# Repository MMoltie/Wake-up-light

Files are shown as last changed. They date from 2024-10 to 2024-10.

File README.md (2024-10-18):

# Wake-up-light

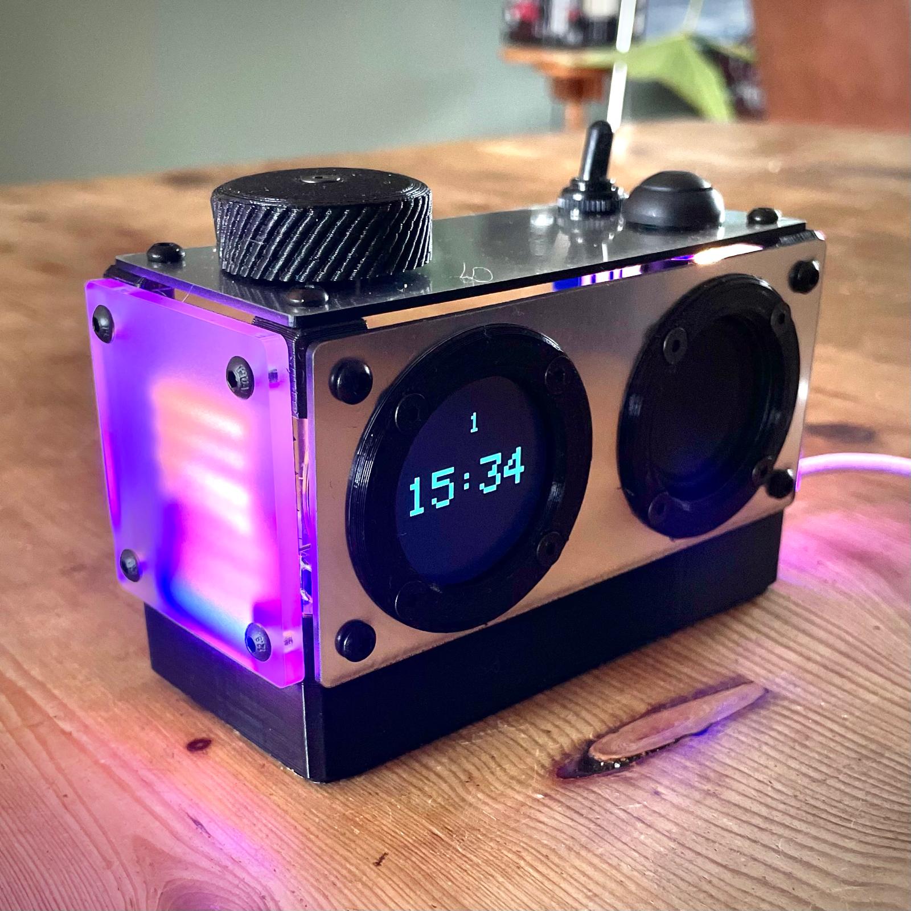
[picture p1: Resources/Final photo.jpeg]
Photo of the projects results


The Wake-up light is a 2-in-1 alarm clock and reading light. 20 minutes before the alarm goes off, LED bars will slowly start to light up, being fully lit and sounding a calming alarm sound when the time to wake is reached. To use the reading light function simply turn the knob to the desired reading time. 10 minutes before the end the lights will slowly dim, helping the reader to gently fall asleep.

#arduino #DIY #wakeup-light #3dprinting #pcb-design #alarmclock 

## Links:

3D model - https://cad.onshape.com/documents/af6c3aa3524b6fd9ad475df8/w/6b9f407a1e785059fe354a23/e/e36683b730fa269897eac513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

PCB - https://oshwlab.com/marliesmoltmaker/wake-up-light_copy

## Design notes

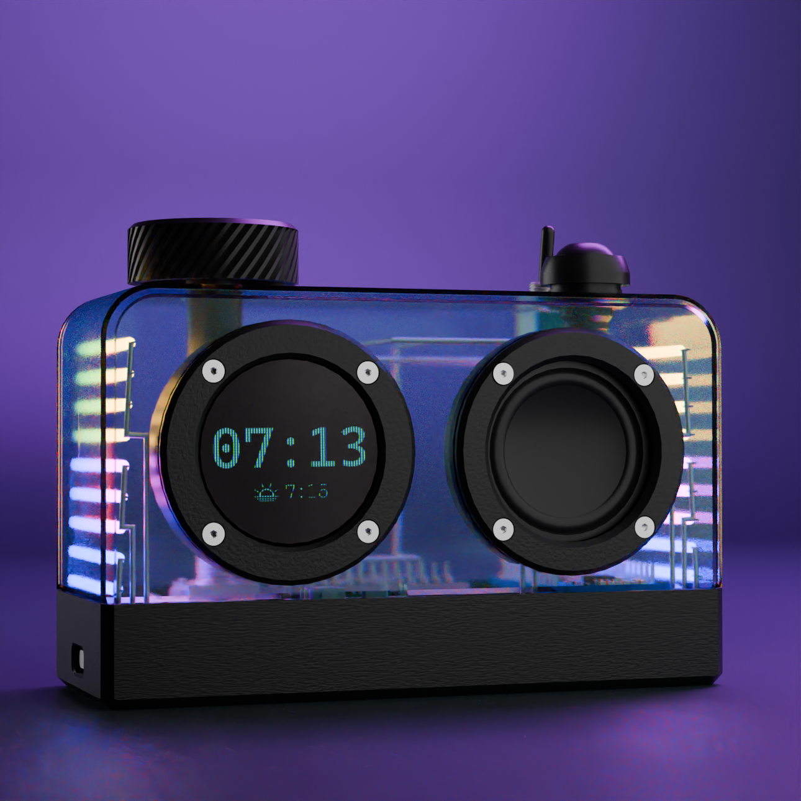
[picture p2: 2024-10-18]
Resources/Render.png

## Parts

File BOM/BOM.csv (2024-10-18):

Qty | Name | Manufacturer | Specification
Purchase
1 | Controller | Arduino | Nano USB-C
1 | RTC | DFRobot | Fermion SD3031
1 | Display |  | 1.28 inch GC9A01
1 | Audio board |  | BY8301-16P
1 | Buck converter |  | MP1584
1 | USB port
3 | Transistor |  | TIP120 60V 5A
4 | LED bar – blue |  | 38mm 3V
6 | LED bar – pruple |  | 38mm 3V
8 | LED bar – orange |  | 38mm 3V
1 | Rotary encoder |  | EC11 15mm half handle
1 | Push Button |  | PBS-33B
1 | Toggle switch |  | MTS-102
1 | Toggle switch cover |  | MTS-XXX
24 | M3 Button |  | M3x6mm, button head
9 | M3 countersunk |  | M3x6mm, countersunk
9 | Insert |  | M3 metal insert
1 | Speaker | Dayton Audio | CE36-8
1 | Wire |  | Single core – 1.5mm
4 | Resistor |  | 1K
1 | Capacitor |  | 1000 uF 25V
Manufacture
1 | Front plate |  | 1.2mm
2 | Side plate |  | 2mm
1 | Back plate |  | 1.2mm
1 | Top plate |  | 1.2mm
1 | Bottom case |  | PLA
4 | Corner connector |  | PLA

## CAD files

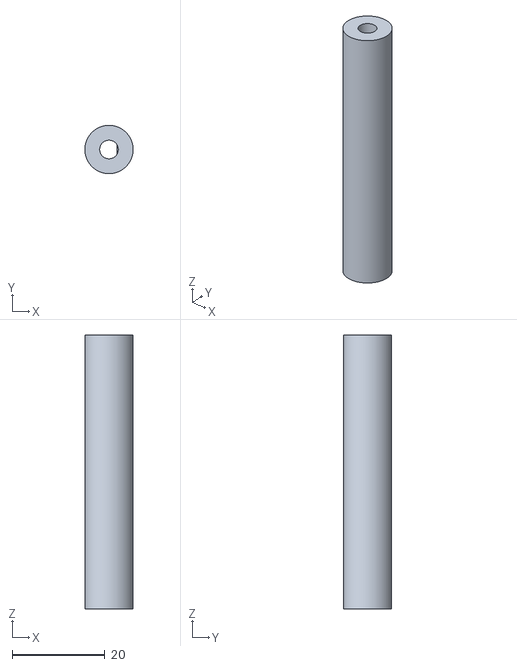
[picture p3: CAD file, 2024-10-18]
CAD/3D print STL/M02003 - Rot knob stem.stl
10.4 x 10.4 x 59.0

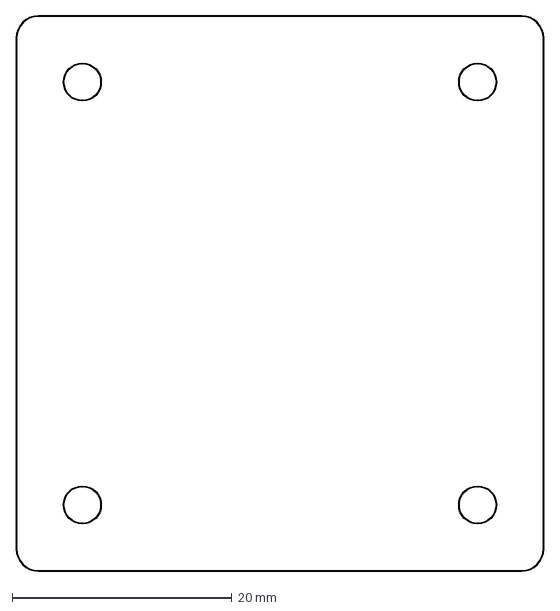
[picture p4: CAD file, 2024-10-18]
CAD/Lasercut STL/M02001d - right plate (2x).dxf
48.0 x 50.5 mm

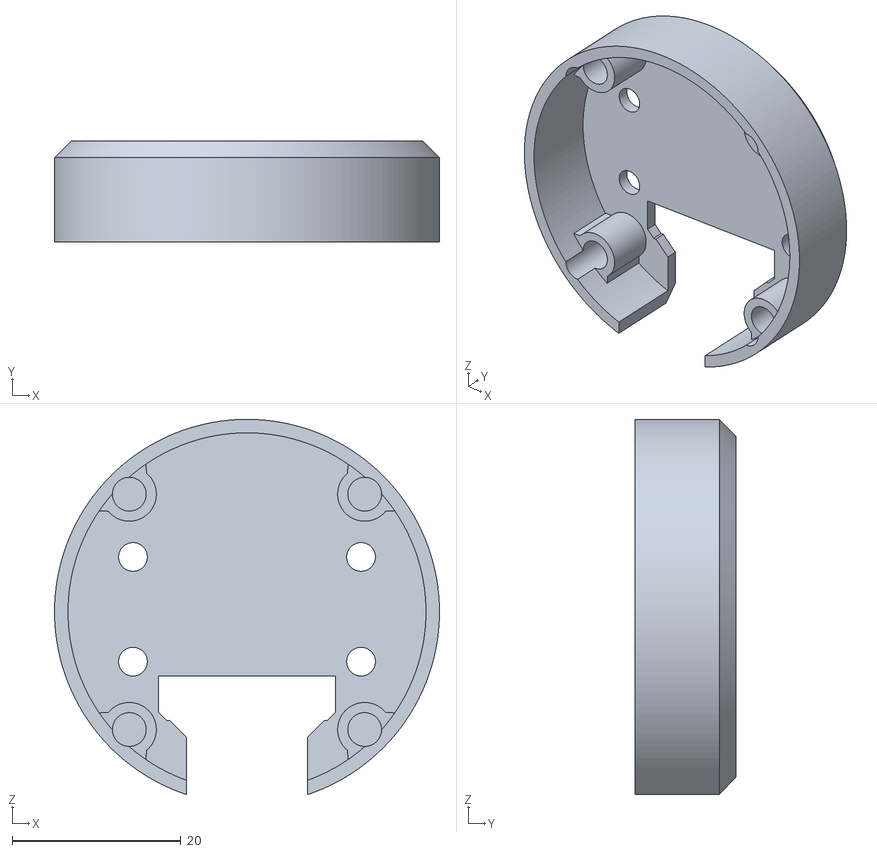
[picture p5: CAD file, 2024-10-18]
CAD/3D print STL/M02007 - Back rim.stl
45.6 x 12.0 x 44.4

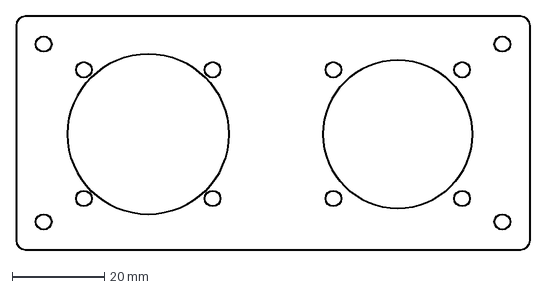
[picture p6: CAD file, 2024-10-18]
CAD/Lasercut STL/M02001a - front plate.dxf
111.3 x 50.5 mm

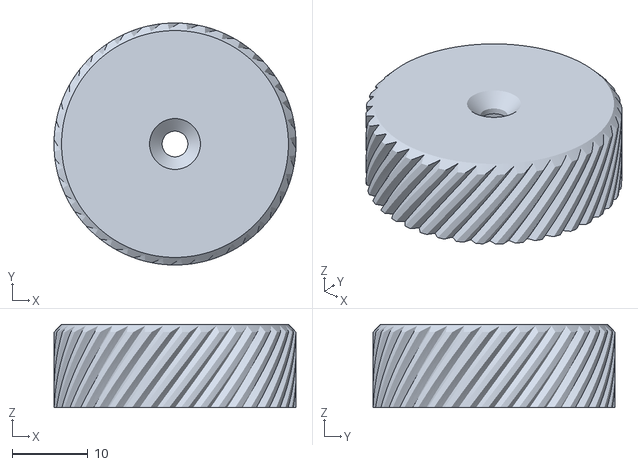
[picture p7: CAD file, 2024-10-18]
CAD/3D print STL/M02003b - Rot knob top.stl
32.0 x 32.0 x 11.0

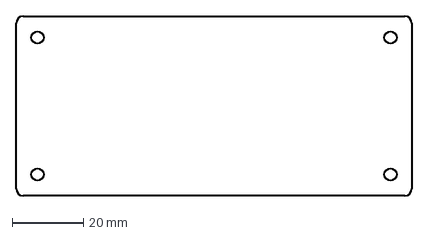
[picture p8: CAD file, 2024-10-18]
CAD/Lasercut STL/M02001b - back plate.dxf
111.3 x 50.5 mm

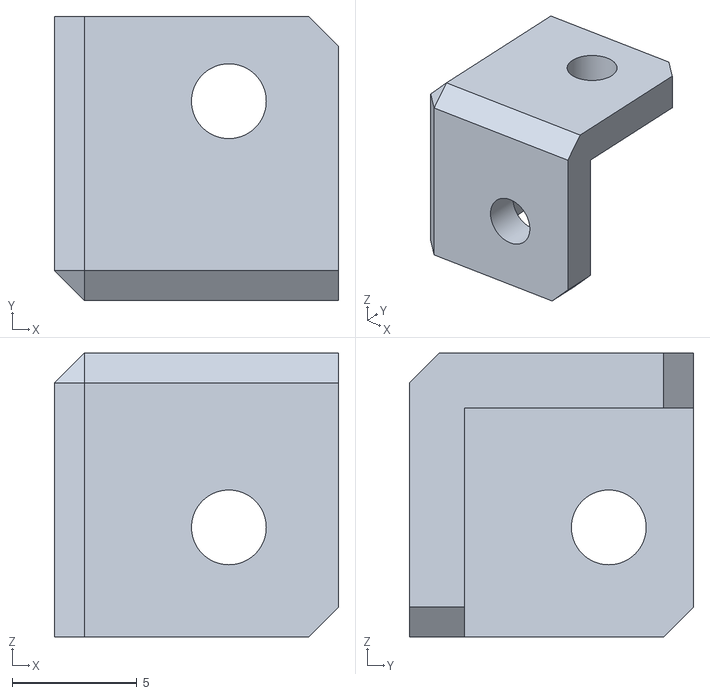
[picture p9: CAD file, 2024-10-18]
CAD/3D print STL/M02010 - CornerConnector.stl
11.4 x 11.4 x 11.4

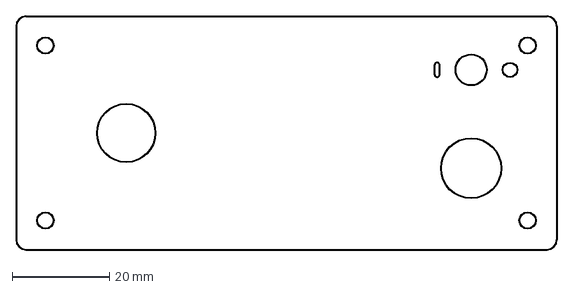
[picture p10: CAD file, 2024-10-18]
CAD/Lasercut STL/M02001e- top plate.dxf
111.3 x 48.0 mm

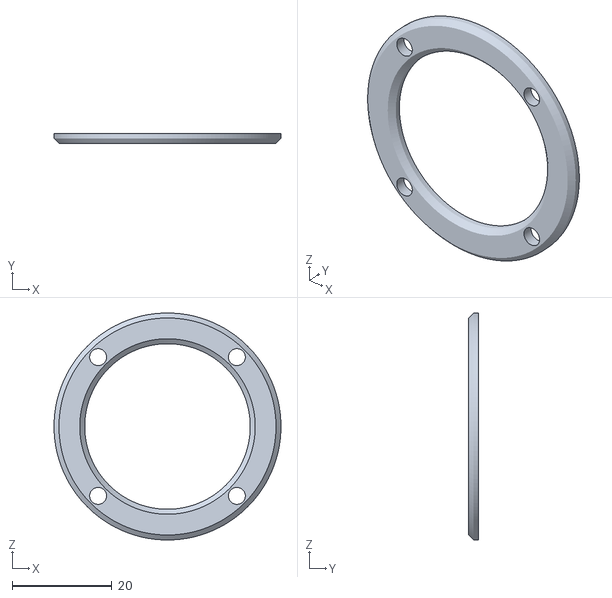
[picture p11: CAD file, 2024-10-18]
CAD/3D print STL/M02006 - Front rim.stl
45.6 x 2.00 x 45.6

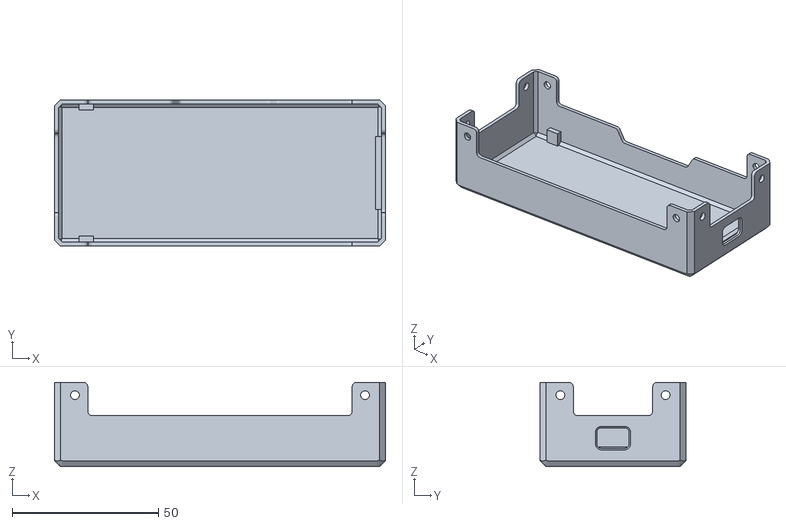
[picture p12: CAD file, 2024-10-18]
CAD/3D print STL/M02002 - Bottom case.stl
113.3 x 50.0 x 28.9

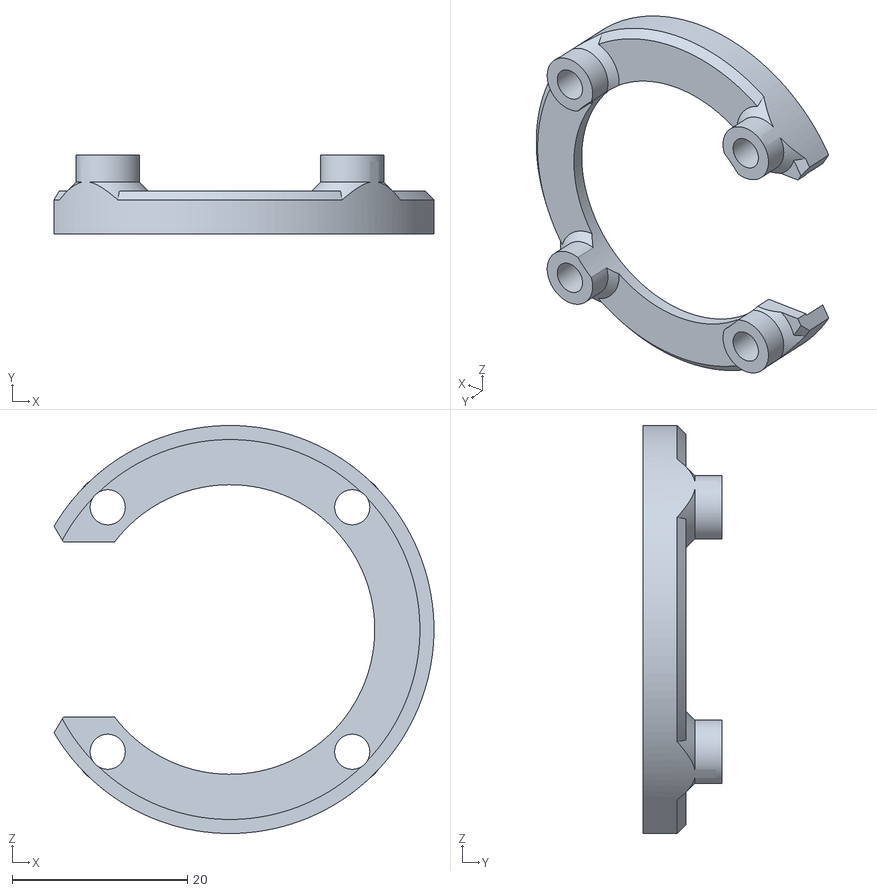
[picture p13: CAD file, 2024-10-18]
CAD/3D print STL/M02009 - Back rim speaker.stl
43.3 x 9.00 x 46.5

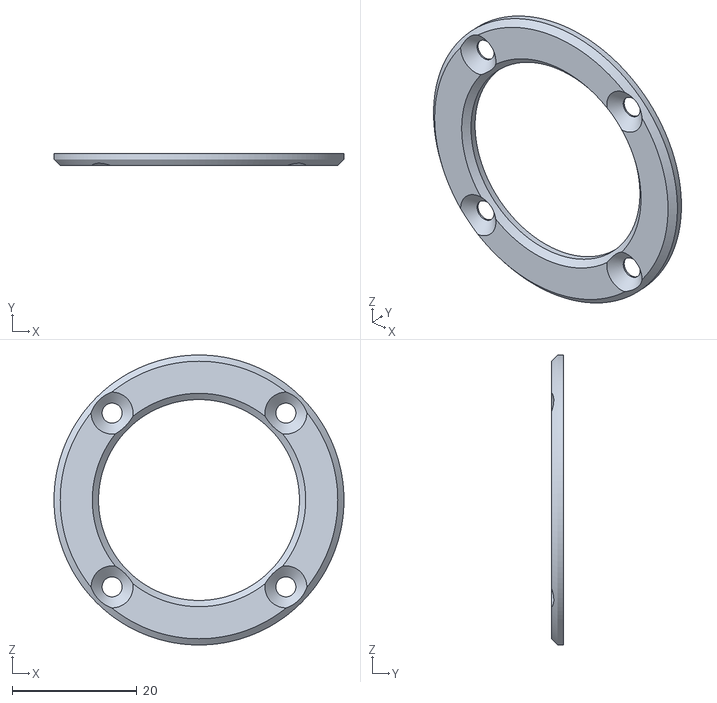
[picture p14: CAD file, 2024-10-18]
CAD/3D print STL/M02008 - Front rim speaker.stl
46.5 x 2.00 x 46.5

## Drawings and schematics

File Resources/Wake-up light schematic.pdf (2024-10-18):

# TFT

# display

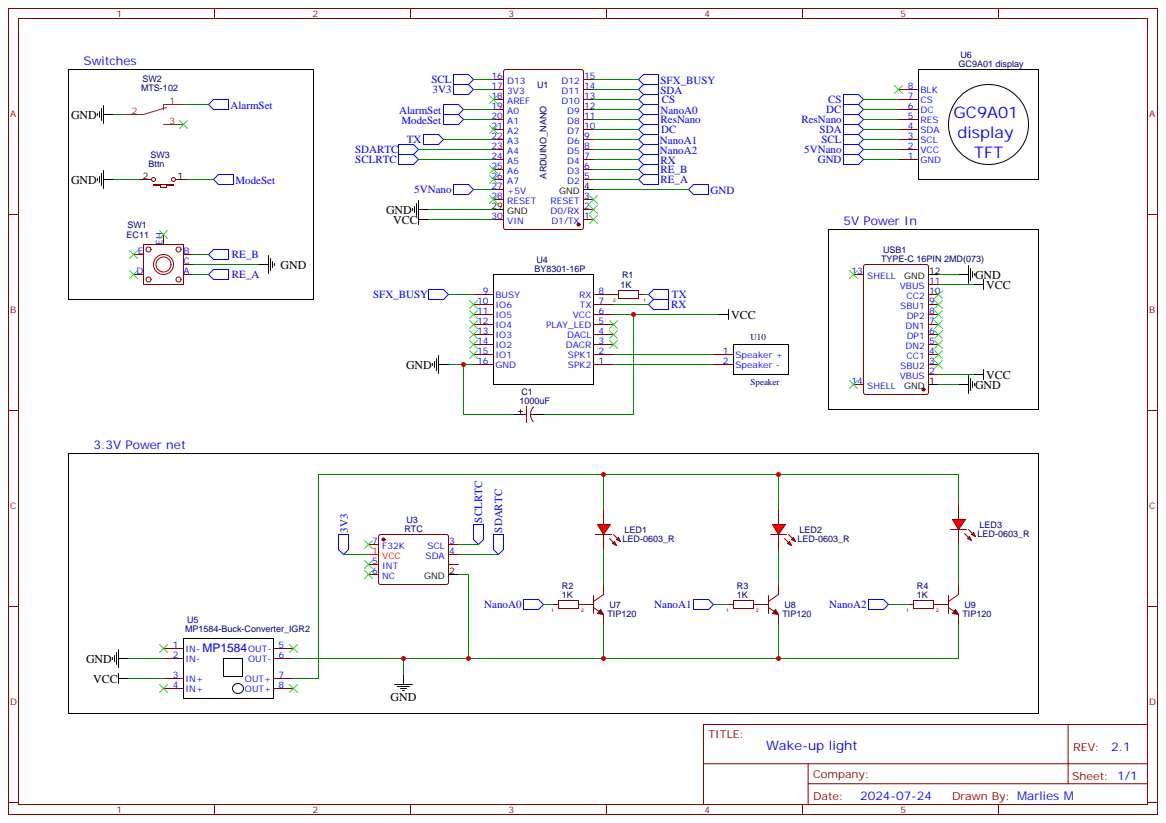
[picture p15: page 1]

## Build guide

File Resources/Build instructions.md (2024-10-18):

# Making
## Display
The display I ordered came with a ribbon cable. I cut the ends off and soldered it directly to the corresponding holes in the PCB. 

## LED arrays
The LED arrays are made by bending the 1.5mm solid core wire into shape and soldering the LED bars to them. I 3D printed a guide to help with correctly bending and cutting the wire to length. The LED bars require quite some heat to solder. I found it easier to solder them onto the wire first, then cutting it to length and bending them.

## RTC module
I made sure to solder the headers in such a way that the battery holder on the RTC module is facing away from the PCB. 

# Music upload
The BY8301-16P is a finicky board. I still not seem to get consistent audio from it. See this GitHub for more information:
https://github.com/NachtRaveVL/BY8X01-16P-Arduino

To upload music:

1. Connect through micro USB
2. A CD-drive folder should appear. Double click to launch.
3. In the screen that opens, go to the second tab.
4. Click on the button, then select the music files you want to upload (be mindful of the limited flash available)
5. Go to the first tab.
6. Click on the button. If you see something similar to "#@%(Flash..." it is uploading the files. If you see something similar to "#%%Flash!" your files are probably too large to upload.

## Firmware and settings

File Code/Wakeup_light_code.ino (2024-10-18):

/*************************************************** 
This code is for a wake-up light with reading light
function. The accompanying settings.h file contains
user settings. 
The general working of the code is that it loops through
various functions at a specific interval. 
It gets the current time from the RTC and checks 
if this time is within an alarm time. 
Then it updates the lights, sound and display accordingly.
***************************************************/

#include "SPI.h"
#include "Adafruit_GFX.h"
#include "Adafruit_GC9A01A.h"
#include "DFRobot_SD3031.h"
#include <Encoder.h>
#include <Wire.h>
#include <SoftwareSerial.h>
#include "Settings.h"
#include "BY8X01-16P.h"



/*----------PINOUT----------*/
//Display
#define TFT_DC 7
#define TFT_CS 10
#define TFT_RES 8

//RTC
//No pinouts defined

//Rotary encoder
#define RE_A 2
#define RE_B 3

//Soundboard
#define SFX_TX A3
#define SFX_RX 4
#define SFX_BUSY 12

//Buttons
#define setButton A1
#define alarmButton A0

//LEDs
#define blueLED 5
#define purpleLED 6
#define orangeLED 9



/*----------Component initialization----------*/
//Display
Adafruit_GC9A01A tft(TFT_CS, TFT_DC, TFT_RES);
int framecount = 0; //variable to keep track of display update periods
int dimcount = 0;

//RTC
DFRobot_SD3031 rtc;

//Rotary encoder
Encoder myEnc(RE_A, RE_B);
long position = 0;

//Soundboard
SoftwareSerial swSerial(SFX_RX, SFX_TX);
BY8X0116P audioController(swSerial);

//Buttons

//LEDs


/*----------Variables----------*/
//Counter variables copied from Generic_RTC_clock
unsigned long prev, interval = 100;     //variables for display and clock update rates (60000 = 1 minute)
int debounceDelay = 50;                 //Debounce for rotary encoder
unsigned long lastDebounceTime = 0;

byte mode = 0;                          //default clock mode
byte alarmCase = 0;                     //alarm case
int readingTime = 0;
float brightnessBlue, brightnessPurple, brightnessOrange, brightnessRL, brightnessLED;

uint8_t alarmSet;                       //Boolean for alarm on or off
uint16_t tempset;                       //Variable to store adjustable time
char timeHour[4];                       //A string to contain "hh" part of time
char timeMin[4];                        //A string to contain "mm" part of time
char alarmTimeHour[4];                  //A string to contain "hh" part of ALARM time
char alarmTimeMin[4];                    //A string to contain "mm" part of ALARM time

//DateTime variables for current time, alarm start time, alarm time and alarmstop time
sTimeData_t t, alarmStart, alarmTime, alarmStop;
unsigned long convertTimetoUnix, convertATtoUnix, alarmStartUnix, alarmStopUnix;
long secToRead, readEnd, dimFlag;



void setup() {
  Serial.begin(115200);

  while (!Serial){
    ; //wait for serial port to open
  }

  Serial.println("Serial communication started.");
  Serial.println("Wake-up light test sequence...");

  //Start display communication and setup
  tft.begin();
  tft.setTextColor(ColorOne, GC9A01A_BLACK);
  tft.fillScreen(GC9A01A_BLACK);
  tft.setRotation(2);
  Serial.println("Display set");

  //Start RTC communication
  while(rtc.begin() != 0){
    Serial.println("Couldn't find RTC");
    delay(500);
  }

  rtc.setHourSystem(rtc.e24hours); //set display to 24hr format
  setCompileTime();
  Serial.println("RTC connected");

  //Start soundboard comm
  swSerial.begin(audioController.getSerialBaud()); //begin softwareserial
  while (!swSerial){
    ; //wait for serial port to open
  }
  Serial.println("Soundboard connected");
  pinMode(SFX_RX, INPUT);
  pinMode(SFX_TX, OUTPUT);

  audioController.init();
  audioController.setVolume(25);

  //Connect buttons and LEDs
  Serial.println("Connecting Buttons and LEDs");
  pinMode(setButton, INPUT_PULLUP);
  pinMode(alarmButton, INPUT_PULLUP);
  pinMode(blueLED, OUTPUT);
  pinMode(purpleLED, OUTPUT);
  pinMode(orangeLED, OUTPUT);

  // Change frequency of LED pins to counter flicker
  TCCR0B = TCCR0B & 0b11111000 | 0x01;  // Set prescaler to 1, frequency = ~62500Hz

  Serial.println("Setup complete!");
}

void loop() {
  unsigned long now = millis();
  long newPos = myEnc.read(); 

  if (now - prev > interval){
    framecount = framecount + 1;
    dimcount = dimcount + 1;
    
    //if enough time has passed, reset the mode to 0 and restart framecount timer
    if (framecount > 20){
      framecount = 0;
      mode = 0;
    }

    //get the current time
    t = rtc.getRTCTime();

    getAlarm();

    updateLights();

    updateSound();

    updateDisplay();

    //depending on the clock mode, change the behaviour of the rotary encoder knob
    switch(mode){
      case 0: //default 
        if (newPos != position){
          dimFlag = millis() + 3600000; //set a flag in 1 minute
          dimcount = 0;

          //If knob is turned, reading time is increased or decreased. First in increments of 1 minute, then 5, then 10.
          if(newPos >= position){
            if(readingTime <= 5){
              readingTime = readingTime + 1;
            } else if (readingTime > 5 && readingTime <=30){
              readingTime = readingTime + 5;
            } else { readingTime = readingTime + 10;}
          } else {
            if(readingTime <= 5){
              readingTime = readingTime - 1;
            } else {readingTime = readingTime - 5;}
            if(readingTime < 0){
              readingTime = 0;
            }  
          }

          readEnd = convertTimetoUnix + (readingTime*60);  //reading end time is current time + readingtime (in Unix)
        }
      break;

      case 1: //Hour adjust
        tempset = t.hour;

        if (newPos != position && (millis() - lastDebounceTime) > debounceDelay){    //if the rotary encoder is turned..
          lastDebounceTime = millis();
          //reset dim and mode timers
          framecount = 0;           
          dimcount = 0;
          
          if (newPos > position){
            tempset = (tempset + 1) % 24;
          } else {
            tempset = (tempset == 0) ? 23: tempset -1;
          }  
          
          rtc.setTime(t.year,t.month,t.day,tempset,t.minute,t.second);
          t = rtc.getRTCTime();
        }
      break;

      case 2: //Minute adjust
        tempset = t.minute;
        
        if (newPos != position){    //if the rotary encoder is turned..
          //reset dim and mode timers
          framecount = 0;           
          dimcount = 0;
          
          if (newPos > position){
            tempset = (tempset + 1) % 60;
          } else {
            tempset = (tempset == 0) ? 59: tempset - 1;
          }  
          
          rtc.setTime(t.year,t.month,t.day,t.hour,tempset,t.second);
          t = rtc.getRTCTime();
        }
      break;

      case 3: //Alarm hour adjust
        tempset = wakeHour;
        
        if (newPos != position){    //if the rotary encoder is turned..
          //reset dim and mode timers
          framecount = 0;           
          dimcount = 0;
          if (newPos > position){
            tempset = (tempset + 1) % 24;
          } else {
            tempset = (tempset == 0) ? 23: tempset - 1;
          }  
          
          wakeHour = tempset;
        }
      break;

      case 4: //Alarm minute adjust
        tempset = wakeMinute;
        
        if (newPos != position){    //if the rotary encoder is turned..
          //reset dim and mode timers
          framecount = 0;           
          dimcount = 0;
          if (newPos > position){
            tempset = (tempset + 1) % 60;
          } else {
            tempset = (tempset == 0) ? 59: tempset - 1;
          }  
          
          wakeMinute = tempset;
        }
      break;

      case 5: //Adjust alarm song
        if (newPos != position){
          //reset dim and mode timers
          framecount = 0;           
          dimcount = 0;
          delay(100);

          if(newPos > position){
            songIndex = (songIndex + 1) % 7;
          } else {
            songIndex = (songIndex == 0) ? 6: songIndex - 1;
          }
        }
      break;

      case 6: //Adjust alarm volume
        if (newPos != position){
          //reset dim and mode timers
          framecount = 0;           
          dimcount = 0;
          if(newPos > position){
            songVolume = (songVolume + 1) % 31;
          } else {
            songVolume = (songVolume == 0) ? 30: songVolume -1;
          }
        }
      break;
      } //end of switch mode block
  
    prev = now;
    position = newPos;

  }//end of update if-statement

  if(!digitalRead(setButton)){
    delay(25);                          //debounce

    if(!digitalRead(setButton)){        //if set button is pressed:
      mode = (mode + 1) % 7;            //increase the mode by one, and rollover at 6
      framecount = 0;                   //reset frame counter
      dimcount = 0;                     //reset dimming counter
      while(!digitalRead(setButton)){}  //wait for button release
    }
  }

  alarmSet = digitalRead(alarmButton);

}//end of loop

//function to set the time of the RTC to the time the code was compiled
void setCompileTime(){
  // Define arrays for month conversion and use sscanf for parsing __DATE__ and __TIME__
  const char monthNames[] = "JanFebMarAprMayJunJulAugSepOctNovDec";
  const char monthStr[4];
  int year, month, day, hour, minute, second;
  
  // Parse compile date and time
  sscanf(__DATE__, "%s %d %d", monthStr, &day, &year);
  sscanf(__TIME__, "%d:%d:%d", &hour, &minute, &second);
  
  // Convert month string (first 3 letters of __DATE__) to a number
  month = (strstr(monthNames, monthStr) - monthNames) / 3 + 1;

  // Set the RTC time
  rtc.setTime(year, month, day, hour, minute, second);
}

void getAlarm(){
  /* 
  This function tells the clock which alarm state it is in. 
  Fist it collects the user's set alarm hh:mm.
  Then it detracts 20 minutes, which is the moment the LED's should start lighting up. This is alarm case 1.
  When the alarm time is reached and for 5 minutes afterwards the LED's should remain being fully lit and an alarm sound plays. This is alarm case 2. 
  Outside of these cases is the default alarm state, case 0.
  */
  
  //alarm time is set to the user's input time;
  alarmTime.day = t.day;
  alarmTime.hour = wakeHour;
  alarmTime.minute = wakeMinute;

  //convert current time into Unix time
  convertTimetoUnix = t.day*216000 + t.hour*3600 + t.minute*60 + t.second;
  //convert alarmtime into Unix time
  convertATtoUnix = alarmTime.day*216000 + alarmTime.hour*3600 + alarmTime.minute*60 + alarmTime.second;
  //subtract 20 minutes from Unix time for alarm start time
  alarmStartUnix = convertATtoUnix - 21*60;
  //add 5 minutes to Unix time for alarm stopping time
  alarmStopUnix = convertATtoUnix + 5*60;

  //compare current time t to alarmstart, alarmtime and alarmstop
  //set alarmCase depending on situation
  //case 0: before AlarmStart, or after AlarmStop
  //case 1: inside of AlarmStart, but before AlarmTime - ramp-up phase
  //case 2: inside AlarmTime, but before AlarmStop - alarm sounding time
  if(convertTimetoUnix < alarmStartUnix){
    alarmCase = 0;
  } else if(convertTimetoUnix >= alarmStartUnix && convertTimetoUnix < convertATtoUnix){
    alarmCase = 1;
  } else if(convertTimetoUnix >= convertATtoUnix && convertTimetoUnix < alarmStopUnix){
    alarmCase = 2;
  } else if(convertTimetoUnix > alarmStopUnix){
    alarmCase = 0;
  } else {
    alarmCase = 0;
  }
}

void updateLights(){
  /*
  This function calculates the brightness of the LEDs in two stages:
  First it checks whether a reading time is set, and sets a readingLight brightness.
  Then it checks which alarm case the clock is in, and sets an alarm brightness.
  At the end the higher of the two brightnesses is passed to the LEDs
  */

  //if a minute has passed: reduce the readingtime with 1
  if(readingTime > 0){
    if(millis() >= dimFlag){
      readingTime = readingTime - 1;
      if(readingTime < 0){
        readingTime = 0;
      }
      dimFlag = millis() + 3600000;  //sets a new flag in 1 minute to reduce the readingtime again
    }
    
    secToRead = max(0, (readEnd - convertTimetoUnix));

    /*
    sets the brightness levels depending on how long there's time left to read:
    >10 minutes: full brightness
    0 minutes: off
    0-10 minutes: dims the LEDs from full brightness (255) to off (0) in the 600 seconds left to read. 
                  This means the LEDs need to dim by 0.425 brightness / second
    */    
    if(readingTime > 10){
      brightnessRL = 255;
    } else if (readingTime == 0){
      brightnessRL = 0;
    } else {
      brightnessRL = 0.425*secToRead;
    }
  } else {
    brightnessRL = 0;
  }
  
  if(alarmSet){
    switch (alarmCase){
      case 0: //before alarmStart or after alarmStop
        brightnessLED = 0;
      break;
      case 1: //within 20 minutes of the set alarm time
        //calculate how many seconds until alarmTime
        unsigned long secsToAlarm = convertATtoUnix - convertTimetoUnix;
        //255 brightness steps / 1200 seconds to alarm = 0.21 brightness/second
        //inverted (255-brightness) to go from off to on
        //max function to prevent below zero calculation of the brightness
        brightnessBlue = max(0, 255 - (secsToAlarm * 0.21));
        //there is an offset between the LEDs; blue first, then red, then orange
        //brightness red = brightness blue - 5min
        //brightness orange = brightness blue - 12min?
        brightnessPurple = max(0, brightnessBlue - (0.21*300));
        brightnessOrange = max(0, brightnessBlue - (0.21*600));
      break;
      case 2: //during alarm
        brightnessLED = 255;
      break;
    }
  } else {
    brightnessLED = 0;
    brightnessBlue = 0;
    brightnessPurple = 0;
    brightnessOrange = 0;
  }
  
  int y = max(brightnessLED, brightnessRL);
  analogWrite(blueLED, max(brightnessBlue, y));
  analogWrite(purpleLED, max(brightnessPurple, y));
  analogWrite(orangeLED, max(brightnessOrange, y));
}

void updateSound(){
  audioController.setVolume(songVolume);
  
  if(alarmSet){
    switch (alarmCase){
      case 0:
        audioController.stop();
      break;
      case 2:
        if(!digitalRead(SFX_BUSY)){
          //songIndex is 0 indexed, while audioplayer needs 1 or higher. Therefore +1
          audioController.playFileIndex(songIndex + 1);
        }
      break;
    }
  }
  if(!alarmSet){
    audioController.stop();
  }
}

void updateDisplay(){
  /*
  Function to update the display.
  1-by-1 it updates the elements on the display: reading time, time, etc. 
  Each element has a dimmed mode or lighter mode to help the user identify which mode the clock is in.
  ie. if the user is adjusting the alarm time hour, this element is highlighted while all the other elements on the clock are dimmed
  The colors of the clock can be adjusted in settings.h
  */
  
  //if enough time has passed; dim the display
  //unless the alarm is going off
  if(dimcount > 30 && dimming && alarmCase != 2){
    tft.fillRect(0, 0, 240, 240, GC9A01A_BLACK);
    return;
  }
  
  //Draw readingTime
  if(readingTime >= 1){
    char readT[4];
    sprintf(readT, "%2d", readingTime);
    if(mode >= 1){
      tft.setTextColor(ColorTwo, GC9A01A_BLACK);
    } else {tft.setTextColor(ColorOne, GC9A01A_BLACK);}
    tft.setCursor(oneCursor_x, oneCursor_y);
    tft.setTextSize(3);
    tft.print(readT);
  } else {
    tft.fillRect(oneCursor_x, oneCursor_y, 136, 21, GC9A01A_BLACK);
  }

  //Draw Time
  if(mode <= 4){
    //convert current time to strings to display
    sprintf(timeHour, "%2hhu", t.hour);
    sprintf(timeMin, "%02hhu", t.minute);
    
    tft.setTextSize(6);
    
    //Draw time "hh"
    tft.setCursor(twoCursor_x, twoCursor_y);
    if(mode >= 2){
      tft.setTextColor(ColorTwo, GC9A01A_BLACK);
    } else {tft.setTextColor(ColorOne, GC9A01A_BLACK);}
    tft.print(timeHour);

    //Draw time ":"
    tft.setCursor(threeCursor_x, threeCursor_y);
    if(mode >= 1){
      tft.setTextColor(ColorTwo, GC9A01A_BLACK);
    } else {tft.setTextColor(ColorOne, GC9A01A_BLACK);}
    tft.print(":");
    
    //Draw time "mm"
    tft.setCursor(fourCursor_x, fourCursor_y);
    if(mode == 0 || mode == 2){
      tft.setTextColor(ColorOne, GC9A01A_BLACK);
    } else {tft.setTextColor(ColorTwo, GC9A01A_BLACK);}
    tft.print(timeMin);
  }

  //Draw song titles and volume
  if(mode >= 5){
    if(framecount < 2){tft.fillRect(0, 0, 240, 240, GC9A01A_BLACK);}
    if(mode == 5){tft.setTextColor(ColorOne, GC9A01A_BLACK);}
    else {tft.setTextColor(ColorTwo, GC9A01A_BLACK);}
    tft.setCursor(fiveCursor_x, fiveCursor_y);
    tft.setTextSize(4);
    tft.print(songs[songIndex]);

    //Draw volume setting
    tft.setCursor(sevenCursor_x, sevenCursor_y);
    if(mode == 6){tft.setTextColor(ColorOne, GC9A01A_BLACK);}
    else {tft.setTextColor(ColorTwo, GC9A01A_BLACK);}
    tft.setTextSize(3);
    tft.print(songVolume);
  }

  //Draw alarm icon and time
  if(mode <= 4){
    //if the alarm is ON, display alarm time
    if(alarmSet){
      sprintf(alarmTimeHour, "%2hhu", wakeHour);
      sprintf(alarmTimeMin, "%02hhu", wakeMinute);

      tft.setTextSize(3);

      //draw icon
      if(mode >= 1){tft.drawBitmap(sixCursor_x, sixCursor_y, sunIcon, 40, 40, ColorTwo);}
      else {tft.drawBitmap(sixCursor_x, sixCursor_y, sunIcon, 40, 40, ColorOne);}
      
      //Draw alarm "hh"
      tft.setCursor(sevenCursor_x, sevenCursor_y);
      if(mode == 0 || mode == 3){
      tft.setTextColor(ColorOne, GC9A01A_BLACK);
      } else {tft.setTextColor(ColorTwo, GC9A01A_BLACK);}
      tft.print(alarmTimeHour);

      //Draw alarm ":"
      tft.setCursor(eightCursor_x, eightCursor_y);
      if(mode == 0){
      tft.setTextColor(ColorOne, GC9A01A_BLACK);
      } else {tft.setTextColor(ColorTwo, GC9A01A_BLACK);}
      tft.print(":");
    
      //Draw alarm "mm"
      tft.setCursor(nineCursor_x, nineCursor_y);
      if(mode == 0 || mode == 4){
      tft.setTextColor(ColorOne, GC9A01A_BLACK);
      } else {tft.setTextColor(ColorTwo, GC9A01A_BLACK);}
      tft.print(alarmTimeMin);
      }

      //if no alarm is set: fill area with black
      else{ tft.fillRect(sixCursor_x, sixCursor_y, 143, 42, GC9A01A_BLACK);}
  }
}

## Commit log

2024-10-14 Create CAD
2024-10-14 Create mkdir CAD
2024-10-18 Uploading of various files (#1)
    * Create new file
    * Create STL folder
    * Add files via upload
    * Update and rename new file to Full CAD model
    * Create Full 3D model
    * Add files via upload
    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
    [BOM.csv, M02001a - front plate.dxf, M02001b - back plate.dxf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]
